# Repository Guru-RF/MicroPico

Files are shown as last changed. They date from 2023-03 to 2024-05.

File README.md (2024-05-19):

# µPico

2022-P-104

RF.Guru µPico PCB [https://shop.rf.guru/products/2023-p-104](https://shop.rf.guru/products/2022-p-104)

RF.Guru µPico PCB Assembled + Enclosure [https://shop.rf.guru/products/2022-pa-104](https://shop.rf.guru/products/2022-pa-104)

# µPico Board Hardware

Schematic [https://github.com/Guru-RF/MicroPico/hw/schematic.pdf](https://github.com/Guru-RF/MicroPico/blob/main/hw/schematic.pdf)

(bom, pick and place, gerber and the stl for the enclosure you can find in https://github.com/Guru-RF/MicroPico/tree/main/hw)

OSHWlab Link [https://oshwlab.com/rf.guru/2022-k-104-picousbstick](https://oshwlab.com/rf.guru/2022-k-104-picousbstick)

# µPico Board Software

In https://github.com/Guru-RF/MicroPico/tree/main/src you can find the sourcecode and lot's of examples

At https://circuitpython.org/board/rfguru_rp2040/ you can find the latest circuitpython firmware for the board !

The source code of circuitpython and our board defination you can find here: [https://github.com/adafruit/circuitpython/tree/main/ports/raspberrypi/boards/rfguru_rp2040](https://github.com/adafruit/circuitpython/tree/main/ports/raspberrypi/boards/rfguru_rp2040)

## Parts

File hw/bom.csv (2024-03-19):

ID | Name | Designator | Footprint | Quantity | Manufacturer Part | Manufacturer | Supplier | Supplier Part | Price
1 | MINI BUZZER | BUZZER1 | MINIBUZZER | 1 | buzzer | null |  | C9900014030
2 | E6C0606RGBC3UDA | LED1,LED2 | LED-SMD_4P-L1.6-W1.6-TL-FD | 2 | E6C0606RGBC3UDA | EKINGLUX | LCSC | C375569 | 0.049
3 | 470 | R6,R1 | R_0402_1005METRIC | 2 |  |  | LCSC | C25117 | 0.001
4 | RP2040 | U5 | LQFN-56_L7.0-W7.0-P0.4-EP | 1 | RP2040 | Raspberry Pi(树莓派) | LCSC | C2040 | 1.076
5 | 1n | C20 | C_0603 | 1 | CL10B102KB8NNNC | SAMSUNG | LCSC | C1588 | 0.003
6 | SRV05-4ATCT | D1 | SOT-23-6_L2.9-W1.6-P0.95-LS2.8-BL | 1 | SRV05-4ATCT | SEMTECH | LCSC | C371093 | 0.34
7 | 220R@100M | FB1,FB2 | L0603 | 2 | UPZ1608E221-2R0TF | Sunlord | LCSC | C98304 | 0.006
8 | 10k | R25 | 0603 | 1 | 0603WAF1002T5E | UniOhm | LCSC | C25804 | 0.001
9 | 100nF | C6,C7,C9,C10,C15,C16,C17 | C_0402_1005METRIC | 7 | CL05B104KO5NNNC | SAMSUNG | LCSC | C1525 | 0.001
10 | 15pF | C11,C12 | C_0402_1005METRIC | 2 | 0402CG150J500NT | FH | LCSC | C1548 | 0.001
11 | 4.7uF | C86 | C_0402_1005METRIC | 1 | CL05A475MP5NRNC | SAMSUNG | LCSC | C23733 | 0.006
12 | 10nF | C87 | C_0402_1005METRIC | 1 | CL05B103KB5NNNC | SAMSUNG | LCSC | C15195 | 0.001
13 | 1K | R3 | R_0402_1005METRIC | 1 | 0402WGF1001TCE | UniOhm | LCSC | C11702 | 0.001
14 | 27 | R4,R5 | R_0402_1005METRIC | 2 | 0402WGF270JTCE | UniOhm | LCSC | C25100 | 0.001
15 | 10kΩ | R11 | R0402 | 1 | 0402WGF1002TCE | UniOhm | LCSC | C25744 | 0.001
16 | B3U-1000P | SW1 | KEY-SMD_B3U-1000PM | 1 | B3U-1000P | Omron Electronics | LCSC | C231329 | 0.148
17 | XC6206P332MR | U8 | SOT-23-3_L2.9-W1.6-P1.90-LS2.8-BR | 1 | XC6206P332MR | TOREX | LCSC | C5446 | 0.104
18 | 12MHz | X2 | CRYSTAL-SMD_4P-L3.2-W2.5-BL | 1 | SMD-3225_4P12M12pf10ppm | TAE | LCSC | C133337 | 0.06
19 | W25Q16FWUXIE TR | U15 | USON8_L2.0-W3.0-P0.50-BL-EP | 1 | W25Q16FWUXIE TR | Winbond Elec | LCSC | C401672 | 0.792

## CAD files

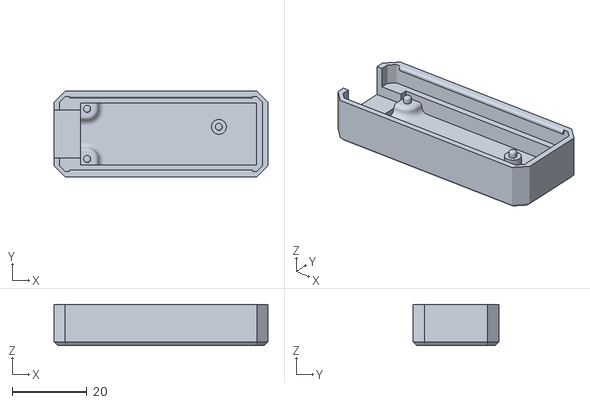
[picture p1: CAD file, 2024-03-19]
hw/enclosure_bottom.stl
57.4 x 23.0 x 11.1

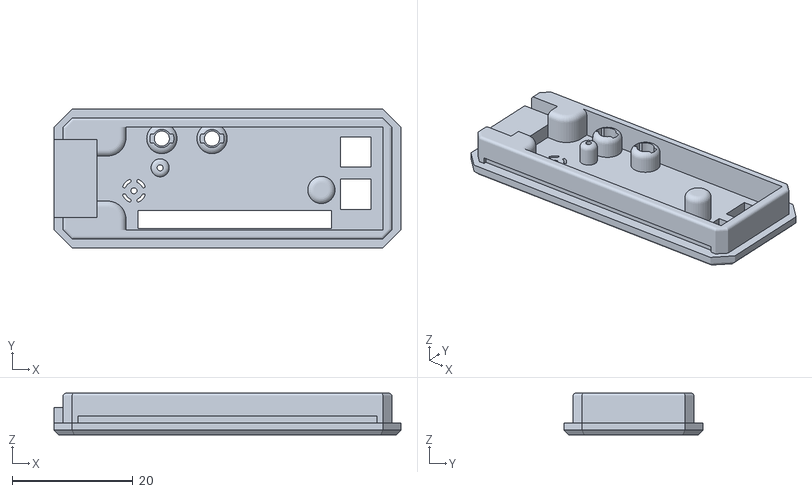
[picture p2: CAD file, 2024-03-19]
hw/enclosure_top.stl
57.4 x 23.0 x 6.90

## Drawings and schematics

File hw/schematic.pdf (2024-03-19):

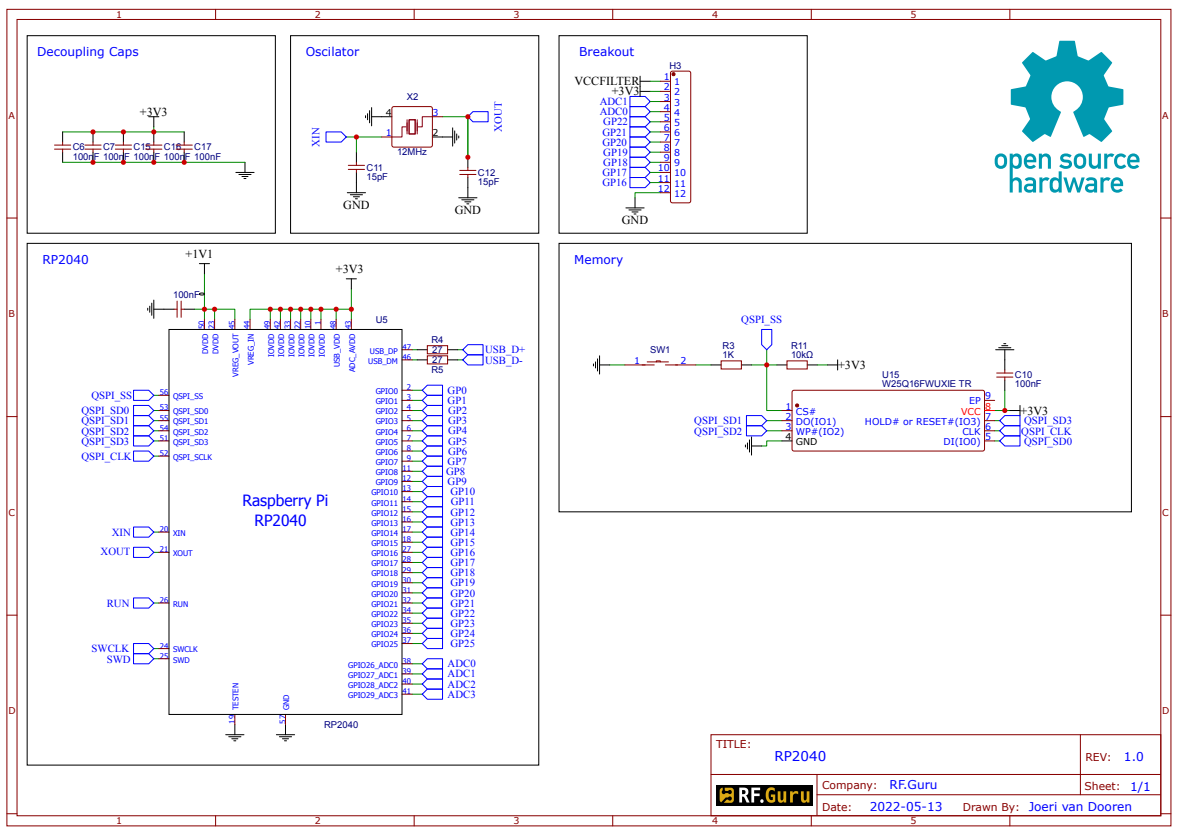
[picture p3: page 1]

TITLE: RP2040 | REV: 1.0

Company: RF.Guru | Sheet: 1/1

Drawn By: Joeri van Dooren

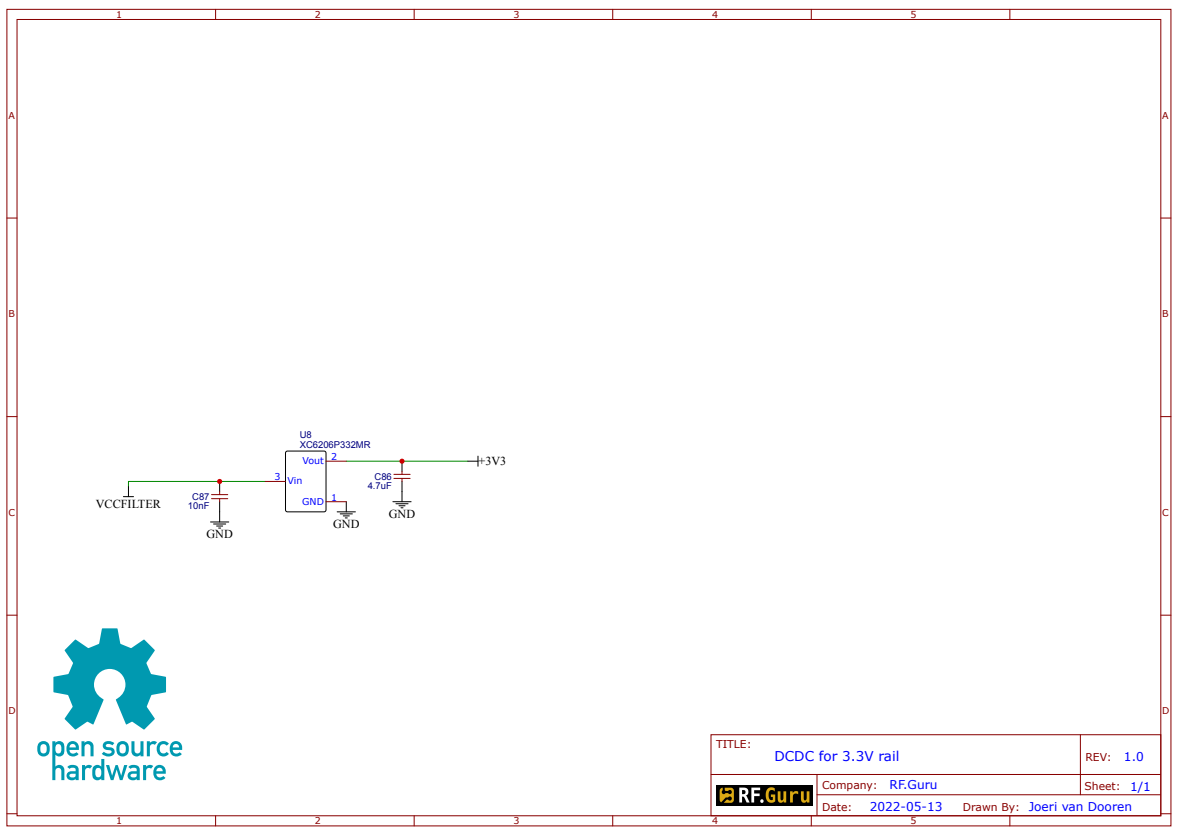
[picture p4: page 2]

TITLE: DCDC for 3.3V rail | REV: 1.0

Company: RF.Guru | Sheet: 1/1

Drawn By: Joeri van Dooren

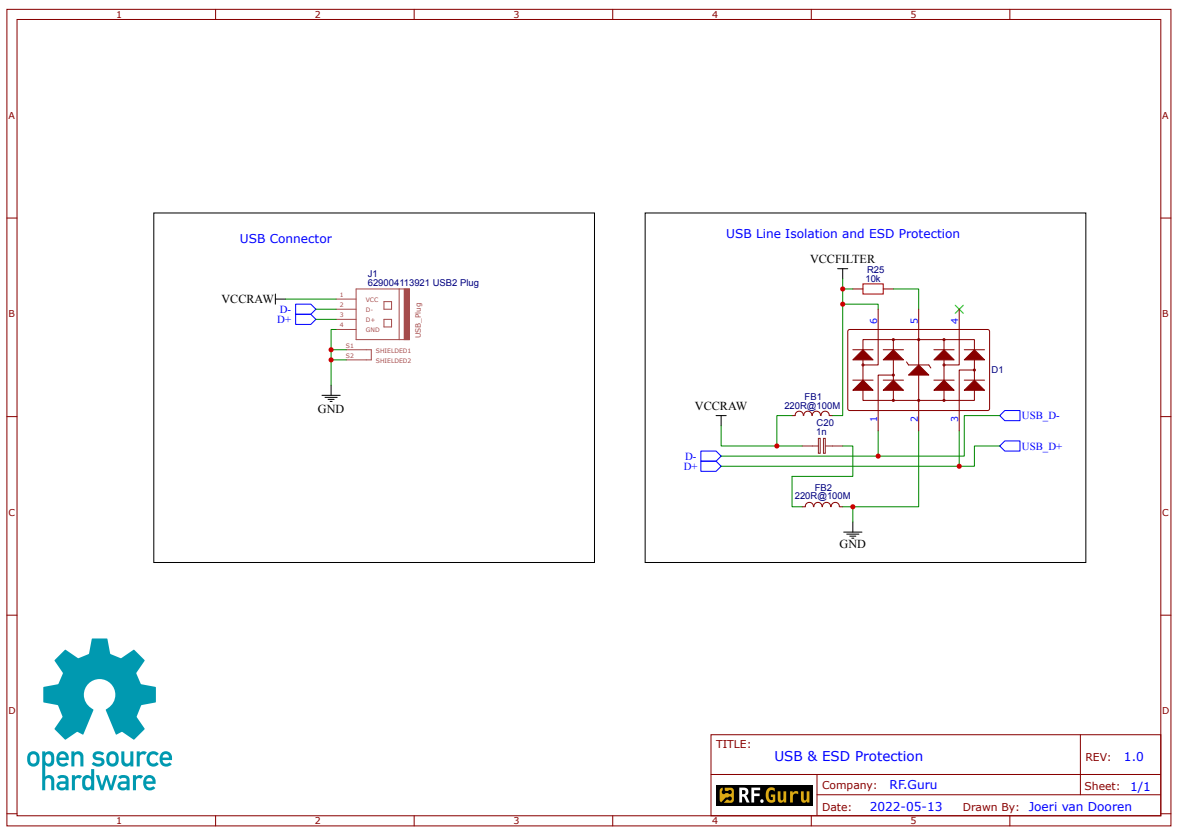
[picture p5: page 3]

USB Line Isolation and ESD Protection

TITLE: USB & ESD Protection | REV: 1.0

Company: RF.Guru | Sheet: 1/1

Drawn By: Joeri van Dooren

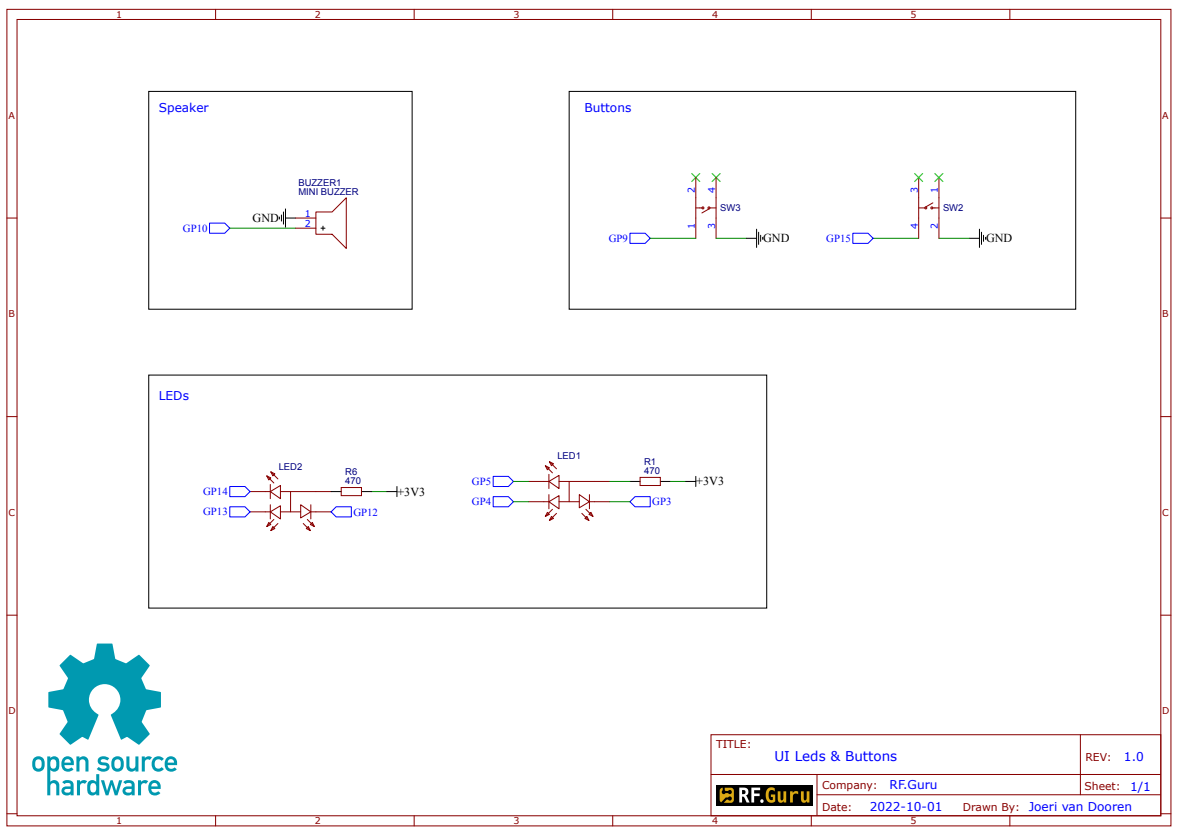
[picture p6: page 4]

TITLE: UI Leds & Buttons | REV: 1.0

Company: RF.Guru | Sheet: 1/1

Drawn By: Joeri van Dooren

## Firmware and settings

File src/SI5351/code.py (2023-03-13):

# Author: Jim Larsen, 2020
# Adapted from Hans Summers Si5351a C code example
# Website: http:www.hanssummers.com

# A very very simple Si5351a demonstration
# Please also refer to SiLabs AN619 which describes all the registers to use

import board
import busio
import adafruit_si5351
import usb_cdc

# setup usb serial
serial = usb_cdc.data

XTAL_FREQ = 25000000
i2c = busio.I2C(board.GP21, board.GP20)
si5351 = adafruit_si5351.SI5351(i2c)

# Set up PLL A with mult, num and denom
# mult is 15..90
# num is 0..1,048,575
# denom is 0..1,048,575

# Set CLK0 output ON and to the specified frequency
# Frequency is in the range 1MHz to 150MHz
# Example: setFrequency(10000000);
# will set output CLK0 to 10MHz

# This example sets up PLL A
# and MultiSynth 0
# and produces the output on CLK0

def setFrequency(frequency):

	xtalFreq = XTAL_FREQ
	
	divider = int(900000000 / frequency) # Calculate the division ratio. 900,000,000 is the maximum internal 
									# PLL frequency: 900MHz
	if (divider % 2): divider -= 1	# Ensure an even integer division ratio
	pllFreq = divider * frequency	# Calculate the pllFrequency: the divider * desired output frequency
	mult = int(pllFreq / xtalFreq)	# Determine the multiplier to get to the required pllFrequency
	l = int(pllFreq % xtalFreq)		# It has three parts:
	f = l							# mult is an integer that must be in the range 15..90
	f *= 1048575					# num and denom are the fractional parts, the numerator and denominator
	f /= xtalFreq					# each is 20 bits (range 0..1048575)
	num = int(f)					# the actual multiplier is  mult + num / denom
	denom = 1048575					# For simplicity we set the denominator to the maximum 1048575

	# Set up PLL A with the calculated multiplication ratio
	# Reset the PLL. This causes a glitch in the output. For small changes to 
	# the parameters, you don't need to reset the PLL, and there is no glitch
	si5351.pll_a.configure_fractional(mult, num, denom)

	# Set up MultiSynth divider 0, with the calculated divider
	# Set the MultiSynth0 input to be PLL A
	# The final R division stage can divide by a power of two, from 1..128. 
	# reprented by constants R_DIV1 to R_DIV128
	# If you want to output frequencies below 1MHz, you have to use the 
	# final R division stage
	# Reset the PLL.
	si5351.clock_0.configure_integer(si5351.pll_a, divider)	
									
	# Finally switch on the CLK0 output
	si5351.outputs_enabled = True

def getFrequency():
	if si5351.clock_0.frequency == None:	# Si5351 not initialized
		setFrequency(28000000)
	return si5351.clock_0.frequency/1000

	print("Clock0 frequency:", getFrequency())
	setFrequency(10000000)	# Set frequency to 10 MHz
	print("Clock0 frequency:", getFrequency())


left = b'\x1b[D'
right = b'\x1b[C'
up = b'\x1b[A'
down = b'\x1b[B'

freq = 7000000
jump = 100

while True:
	if serial.connected:
		if serial.in_waiting > 0:
			letter = serial.read(3)
			if letter == left:
				freq=freq-jump
			if letter == right:
				freq=freq+jump
			if letter == up:
				if jump > 1:
					jump=jump*10
				if jump > 10000:
					jump=10000
			if letter == down:
				if jump > 10:
					jump=jump/10
				if jump < 10:
					jump=10
			setFrequency(freq)
			print("Clock0 frequency:", getFrequency())
	

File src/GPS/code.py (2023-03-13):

import time
import board
import busio

import adafruit_gps

uart = busio.UART(board.GP16, board.GP17, baudrate=9600, timeout=10)

# for a computer, use the pyserial library for uart access
# import serial
# uart = serial.Serial("/dev/ttyUSB0", baudrate=9600, timeout=10)

# If using I2C, we'll create an I2C interface to talk to using default pins
# i2c = board.I2C()

# Create a GPS module instance.
gps = adafruit_gps.GPS(uart, debug=False)  # Use UART/pyserial
# gps = adafruit_gps.GPS_GtopI2C(i2c, debug=False)  # Use I2C interface

# Initialize the GPS module by changing what data it sends and at what rate.
# These are NMEA extensions for PMTK_314_SET_NMEA_OUTPUT and
# PMTK_220_SET_NMEA_UPDATERATE but you can send anything from here to adjust
# the GPS module behavior:
#   https://cdn-shop.adafruit.com/datasheets/PMTK_A11.pdf

# Turn on the basic GGA and RMC info (what you typically want)
gps.send_command(b"PMTK314,0,1,0,1,0,0,0,0,0,0,0,0,0,0,0,0,0,0,0")
# Turn on just minimum info (RMC only, location):
# gps.send_command(b'PMTK314,0,1,0,0,0,0,0,0,0,0,0,0,0,0,0,0,0,0,0')
# Turn off everything:
# gps.send_command(b'PMTK314,0,0,0,0,0,0,0,0,0,0,0,0,0,0,0,0,0,0,0')
# Turn on everything (not all of it is parsed!)
# gps.send_command(b'PMTK314,1,1,1,1,1,1,0,0,0,0,0,0,0,0,0,0,0,0,0')

# Set update rate to once a second (1hz) which is what you typically want.
gps.send_command(b"PMTK220,1000")
# Or decrease to once every two seconds by doubling the millisecond value.
# Be sure to also increase your UART timeout above!
# gps.send_command(b'PMTK220,2000')
# You can also speed up the rate, but don't go too fast or else you can lose
# data during parsing.  This would be twice a second (2hz, 500ms delay):
# gps.send_command(b'PMTK220,500')

# Main loop runs forever printing the location, etc. every second.
last_print = time.monotonic()
while True:
    # Make sure to call gps.update() every loop iteration and at least twice
    # as fast as data comes from the GPS unit (usually every second).
    # This returns a bool that's true if it parsed new data (you can ignore it
    # though if you don't care and instead look at the has_fix property).
    gps.update()
    # Every second print out current location details if there's a fix.
    current = time.monotonic()
    if current - last_print >= 1.0:
        last_print = current
        if not gps.has_fix:
            # Try again if we don't have a fix yet.
            print("Waiting for fix...")
            continue
        # We have a fix! (gps.has_fix is true)
        # Print out details about the fix like location, date, etc.
        print("=" * 40)  # Print a separator line.
        print(
            "Fix timestamp: {}/{}/{} {:02}:{:02}:{:02}".format(
                gps.timestamp_utc.tm_mon,  # Grab parts of the time from the
                gps.timestamp_utc.tm_mday,  # struct_time object that holds
                gps.timestamp_utc.tm_year,  # the fix time.  Note you might
                gps.timestamp_utc.tm_hour,  # not get all data like year, day,
                gps.timestamp_utc.tm_min,  # month!
                gps.timestamp_utc.tm_sec,
            )
        )
        print("Latitude: {0:.6f} degrees".format(gps.latitude))
        print("Longitude: {0:.6f} degrees".format(gps.longitude))
        print("Fix quality: {}".format(gps.fix_quality))
        # Some attributes beyond latitude, longitude and timestamp are optional
        # and might not be present.  Check if they're None before trying to use!
        if gps.satellites is not None:
            print("# satellites: {}".format(gps.satellites))
        if gps.altitude_m is not None:
            print("Altitude: {} meters".format(gps.altitude_m))
        if gps.speed_knots is not None:
            print("Speed: {} knots".format(gps.speed_knots))
        if gps.track_angle_deg is not None:
            print("Track angle: {} degrees".format(gps.track_angle_deg))
        if gps.horizontal_dilution is not None:
            print("Horizontal dilution: {}".format(gps.horizontal_dilution))
        if gps.height_geoid is not None:
            print("Height geo ID: {} meters".format(gps.height_geoid))

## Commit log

2022-11-11 add rotary encoder
2023-03-04 add lora and i2cscan
2023-03-13 new sensors
2023-03-27 default spi display support
2024-03-19 add stl files
    [enclosure_bottom.stl, enclosure_top.stl]
